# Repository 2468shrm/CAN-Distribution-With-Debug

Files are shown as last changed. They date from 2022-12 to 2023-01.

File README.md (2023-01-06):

# CAN-Distribution-With-Debug

## Board Layout
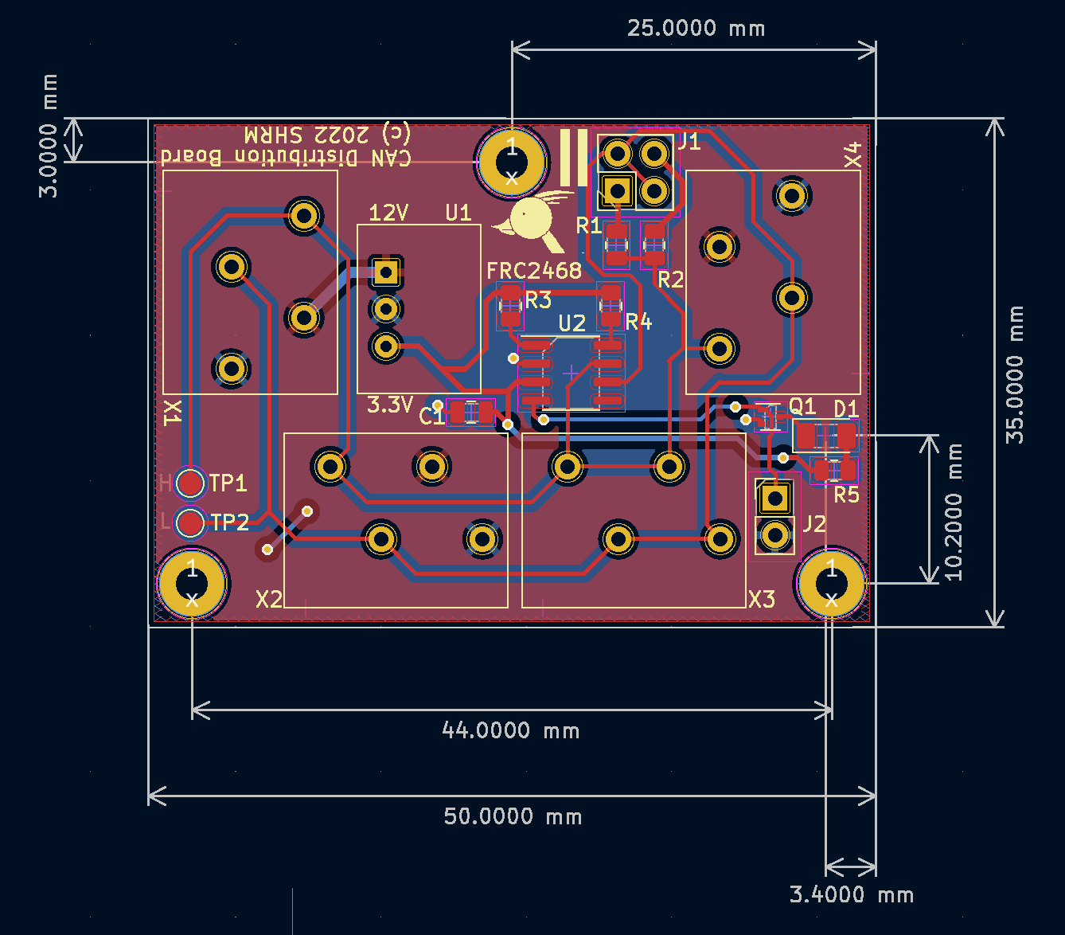
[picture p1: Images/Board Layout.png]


## Disclaimer
This board has not been fabricated or tested. It is to be considered
alpha and subject to bugs and errors. Use at your own risk. However the Gerbers
are provided should you want to fabricate your own.

The board is designed with KiCAD, the schematic and PCB files are included.

## Enclosure

An 3D-printable enclosure is avaiable for this board. [Enclosure link](https://github.com/2468shrm/CAN-Distribution-Board-Enclosure)

## Introduction
This is a board created to simplify CAN wiring on FRC robots. It was created by the
mentors of FRC2468/2687/2689.

### Board Schematic

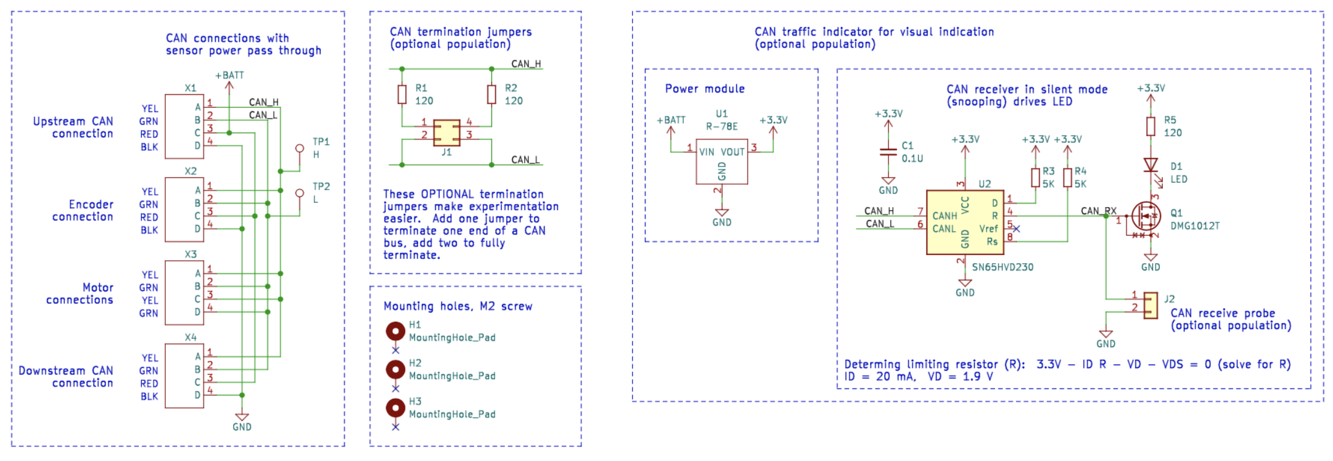
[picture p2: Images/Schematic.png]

The PDF of the schematic is available at this [schematic link](https://github.com/2468shrm/CAN-Distribution-With-Debug/blob/main/Images/Schematic.pdf)

### Features

The board has 5 CAN connections and 3 power connections. The intended use is for
the CAN connections of either a swerve module or a WCD gearbox.
- Power
  - One connection upstream
  - One connection downstream
  - One connection to a local sensor (e.g. a CANcoder)
- CAN
  - One connection upstream
  - One connection downstream
  - One connection to a drive motor controller (Falcon 500, SPARK MAX)
  - One connection to a drive or steering motor
  - One connection to a CAN-connected sensor (CANcoder)

## CAN and Power Connections
The connectors for the CAN and power are WAGO 250-204s (X1, X2, X3, X4).

## Termination
The board contains a 2x2 header (J1) to allow for jumpers to be installed to enable
CAN termination.
- No jumpers means no termination
- One jumper provides 120 ohms termination (single end termination)
- Two jumpers provides 60 ohms termination (full termination)

Populating the termination circuitry is optional.

## Debug
This board also has some experimental CAN debug features. It contains a small power
supply module, a CAN transceiver, and an LED.

The LED is intended to show CAN traffic. It should flicker during traffic; although
the light may just be different intensities and not discrete flickers.

The CAN transceiver is configured in silent mode and the transmit is wired high to
ensure the transceiver is in tristate (recessive).

There are also two test points on the CAN_H and CAN_L signals.

Populating the debug circuitry is optional.

# 3D Views of the Board
## Top
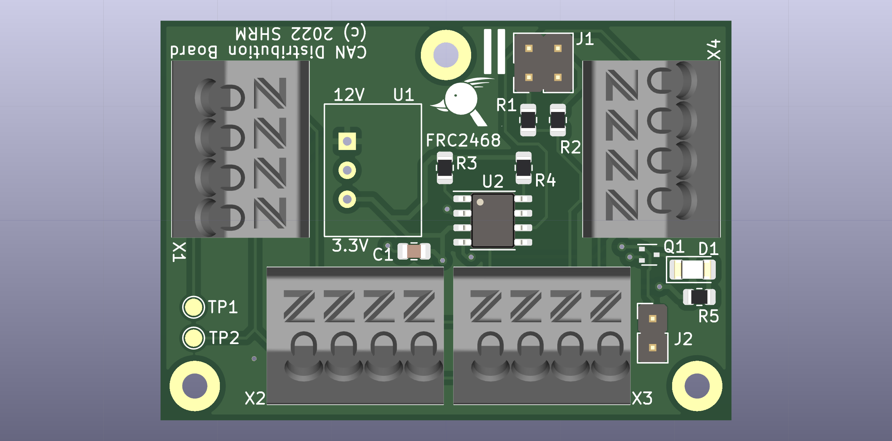
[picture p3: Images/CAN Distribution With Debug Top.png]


## Iso Front
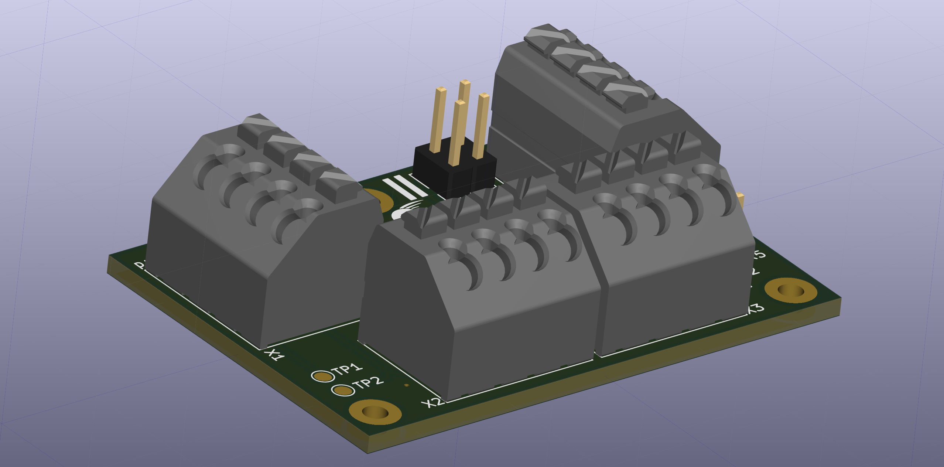
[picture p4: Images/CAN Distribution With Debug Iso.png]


## Iso Back
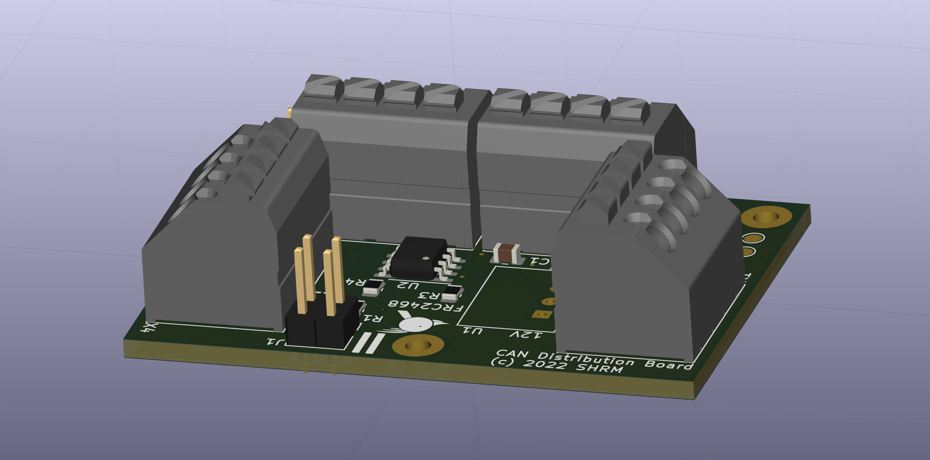
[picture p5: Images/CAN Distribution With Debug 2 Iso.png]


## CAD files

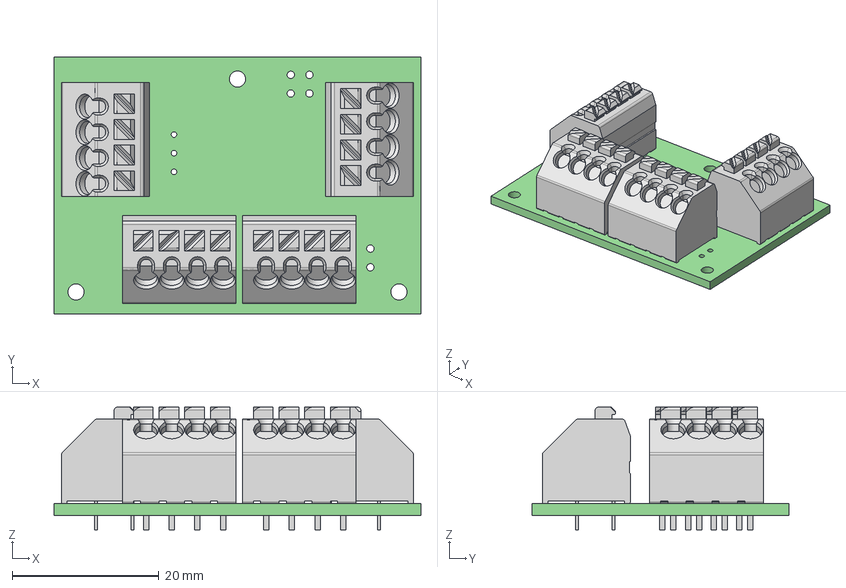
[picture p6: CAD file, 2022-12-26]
STEP/CAN Distribution With Debug.step
50.0 x 35.0 x 16.7 mm
CAN Distribution With Debug PCB

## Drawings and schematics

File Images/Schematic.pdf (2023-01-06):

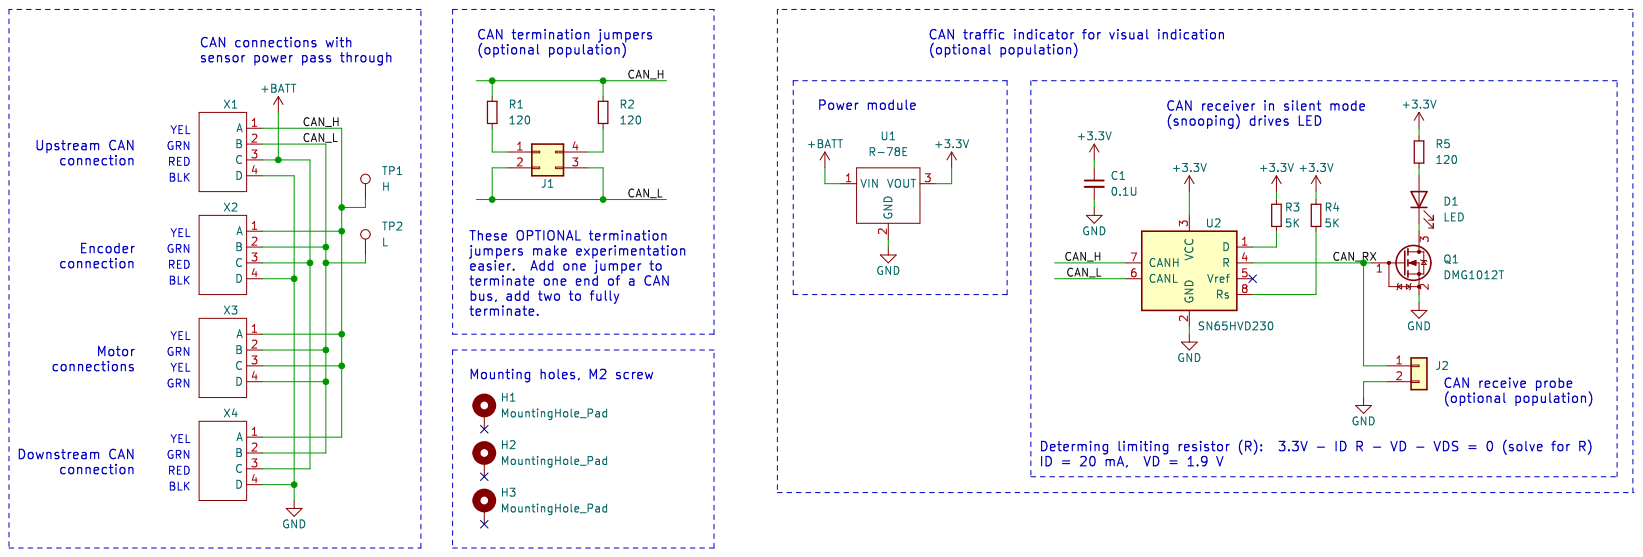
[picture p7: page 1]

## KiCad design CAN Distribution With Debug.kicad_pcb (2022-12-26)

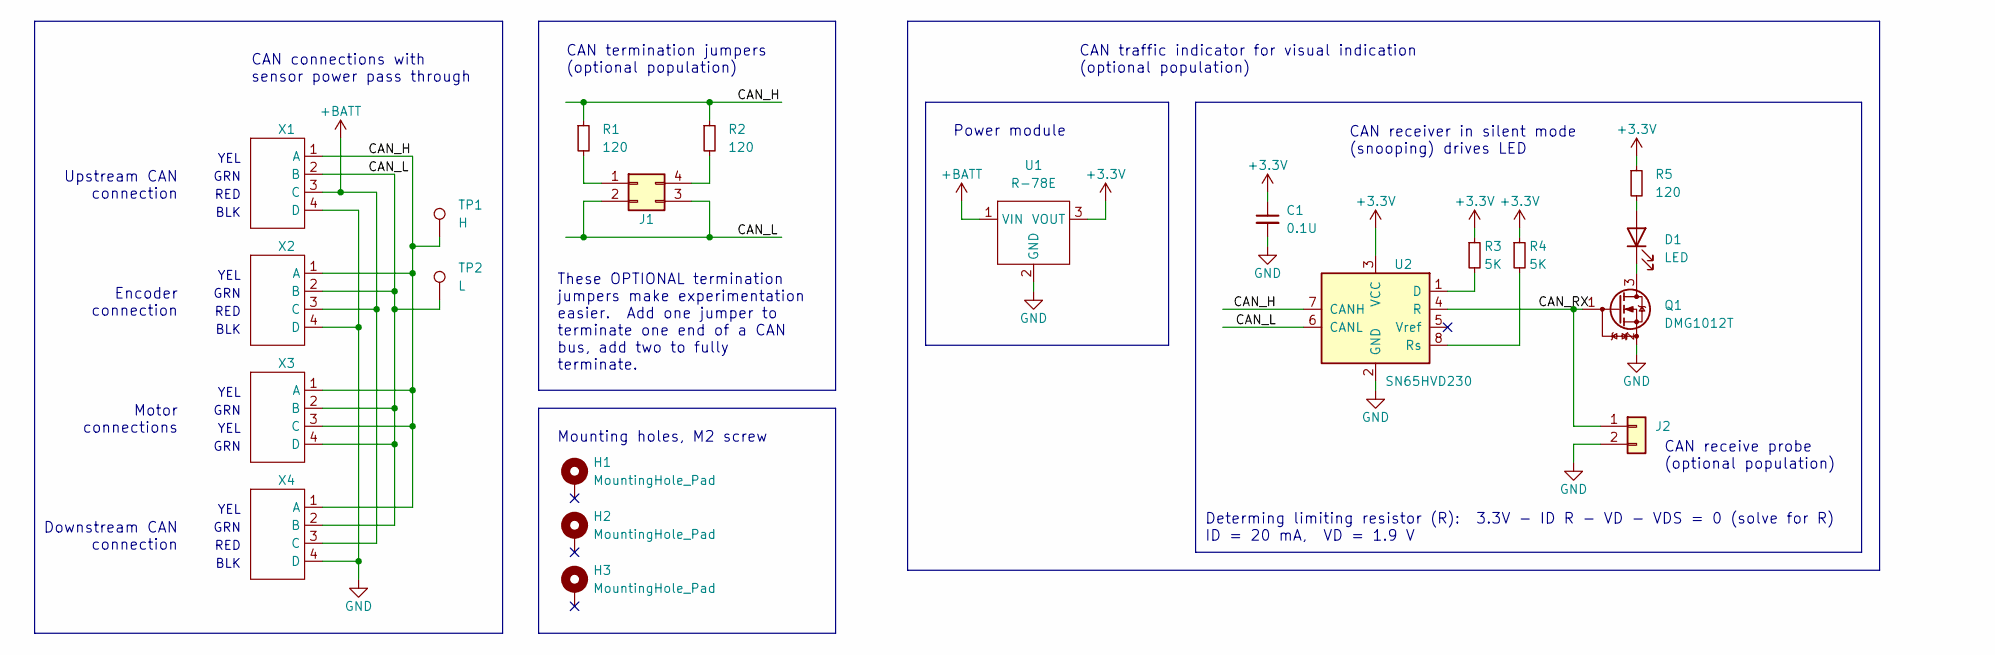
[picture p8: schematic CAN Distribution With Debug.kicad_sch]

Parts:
C1: 0.1U; C_0805_2012Metric
D1: LED; LED_1206_3216Metric
H1, H2, H3: MountingHole_Pad; MountingHole_2.2mm_M2_Pad
J1: Conn_02x02_Counter_Clockwise; PinHeader_2x02_P2.54mm_Vertical
J2: Conn_01x02; PinHeader_1x02_P2.54mm_Vertical
Q1: DMG1012T; SOT-523
R1, R2, R5: 120; R_0805_2012Metric
R3, R4: 5K; R_0805_2012Metric
TP1: H; TestPoint_Pad_D1.5mm
TP2: L; TestPoint_Pad_D1.5mm
U1: R-78E
U2: SN65HVD230; SOIC-8_3.9x4.9mm_P1.27mm
X1, X2, X3, X4: WAGO_250-204; WAGO 250-204

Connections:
+3.3V: C1.1, R3.1, R4.1, R5.1, U1.3 (VOUT), U2.3 (VCC)
+BATT: U1.1 (VIN), X1.3 (C), X2.3 (C), X4.3 (C)
/CAN_H: R1.1, R2.1, TP1.1, U2.7 (CANH), X1.1 (A), X2.1 (A), X3.1 (A), X3.3 (C), X4.1 (A)
/CAN_L: J1.2, J1.3, TP2.1, U2.6 (CANL), X1.2 (B), X2.2 (B), X3.2 (B), X3.4 (D), X4.2 (B)
/CAN_RX: J2.1, Q1.1 (G), U2.4 (R)
GND: C1.2, J2.2, Q1.2 (S), U1.2 (GND), U2.2 (GND), X1.4 (D), X2.4 (D), X4.4 (D)
unnamed: D1.1 (K), Q1.3 (D)
unnamed: D1.2 (A), R5.2
unnamed: J1.1, R1.2
unnamed: J1.4, R2.2
unnamed: R3.2, U2.1 (D)
unnamed: R4.2, U2.8 (Rs)

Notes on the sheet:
BLK
GRN
CAN receive probe (optional population)
YEL
CAN termination jumpers (optional population)
Encoder connection
CAN receiver in silent mode (snooping) drives LED
Determing limiting resistor (R): 3.3V - ID R - VD - VDS = 0 (solve for R) ID = 20 mA, VD = 1.9 V
RED
Upstream CAN connection
CAN traffic indicator for visual indication (optional population)
Mounting holes, M2 screw
These OPTIONAL termination jumpers make experimentation easier. Add one jumper to terminate one end of a CAN bus, add two to fully terminate.
CAN connections with sensor power pass through
Power module
Motor connections
Downstream CAN connection

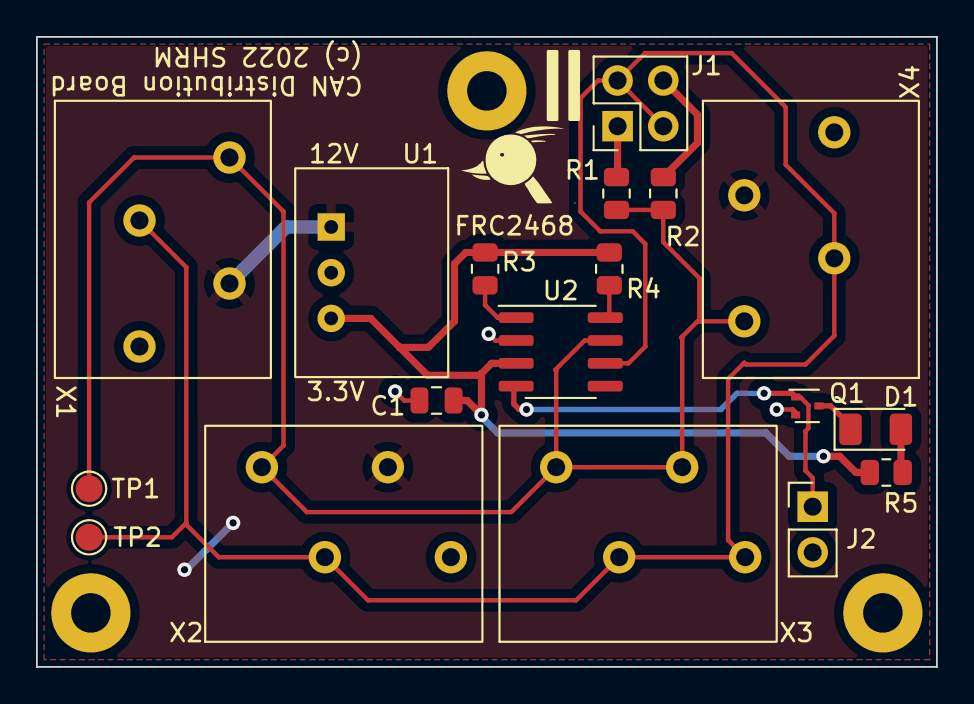
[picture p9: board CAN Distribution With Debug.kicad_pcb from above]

Board: 2 copper layers, 50.0 x 35.0 mm, 21 parts (0 on the bottom side), 12 nets.

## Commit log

2022-12-26 initial design files
    [CAN Distribution With Debug-B_Cu.gbr, CAN Distribution With Debug-B_Mask.gbr, CAN Distribution With Debug-B_Paste.gbr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]
2023-01-06 added enclosure link to README
2023-01-06 added Gerber ZIP file
2023-01-06 added schematic image
2023-01-06 added schematic PNG
2023-01-06 updated README with schematic info
2023-01-07 removing Gerbers.zip
2023-01-07 updated Gerbers.zip (added back)

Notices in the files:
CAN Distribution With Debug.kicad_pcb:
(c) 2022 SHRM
